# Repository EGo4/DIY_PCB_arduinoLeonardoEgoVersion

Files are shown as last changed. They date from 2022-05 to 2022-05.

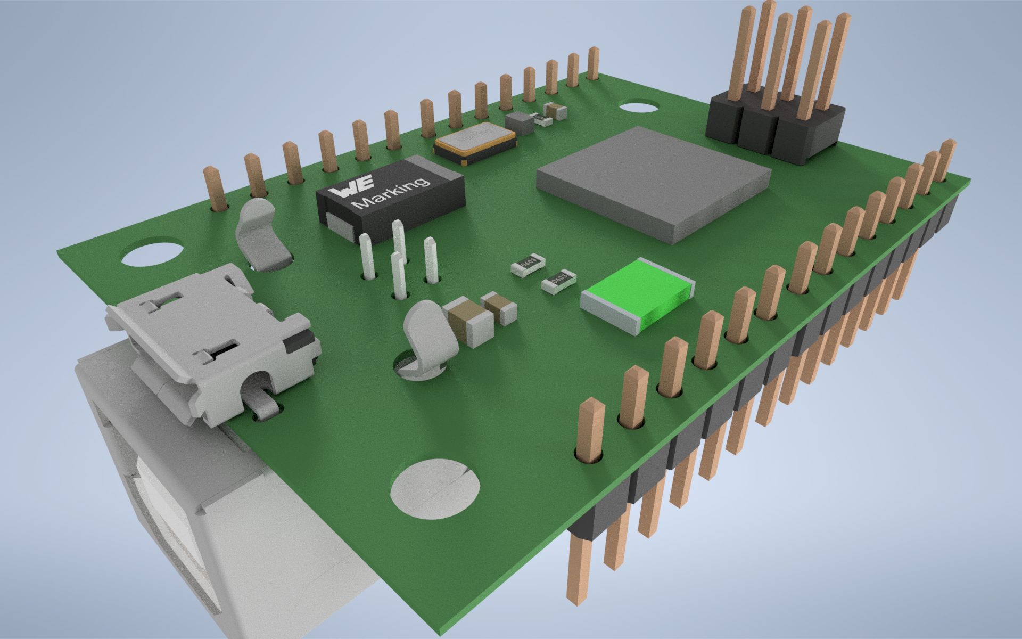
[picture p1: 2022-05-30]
Renderings/arduinoLeonardoEgoVersion.png

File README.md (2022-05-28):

# DIY_arduinoLeonardoEgoVersion
This PCB is an Atmega32u4 based microcontroller board. It can be flashed so that it reports as an Arduino Leonardo or Pro Micro. I am using it in multiple projects like a sim racing wheel for example. The files where created with Altium 18. Step file and gerber files can be found in the repository as well.

This is NOT considered to be an open-source project. Thus any commercial use is prohibited by the owner. Copying and mofying the files for private use is permitted.

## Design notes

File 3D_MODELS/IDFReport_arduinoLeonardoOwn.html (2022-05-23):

Altium customize

# IDF File Translation Report

Date: | | 04.07.2021
Time: | | 13:42:24
Elapsed Time: | | 00:00:00
PCB Filename | : | C:\Users\Eric\Documents\Simulator\PCB\arduinoLeonardoOwn\arduinoLeonardoOwn.PcbDoc
IDF Board Filename | : | C:\Users\Eric\Documents\Simulator\PCB\arduinoLeonardoOwn\.\3D_MODELS\arduinoLeonardoOwn.brd
IDF Library Filename | : | C:\Users\Eric\Documents\Simulator\PCB\arduinoLeonardoOwn\.\3D_MODELS\arduinoLeonardoOwn.pro

Errors

Back to top

Warnings

Back to top

Save Warnings

Back to top

Save Errors

Back to top

Export Warnings

Back to top

Export Errors

Back to top

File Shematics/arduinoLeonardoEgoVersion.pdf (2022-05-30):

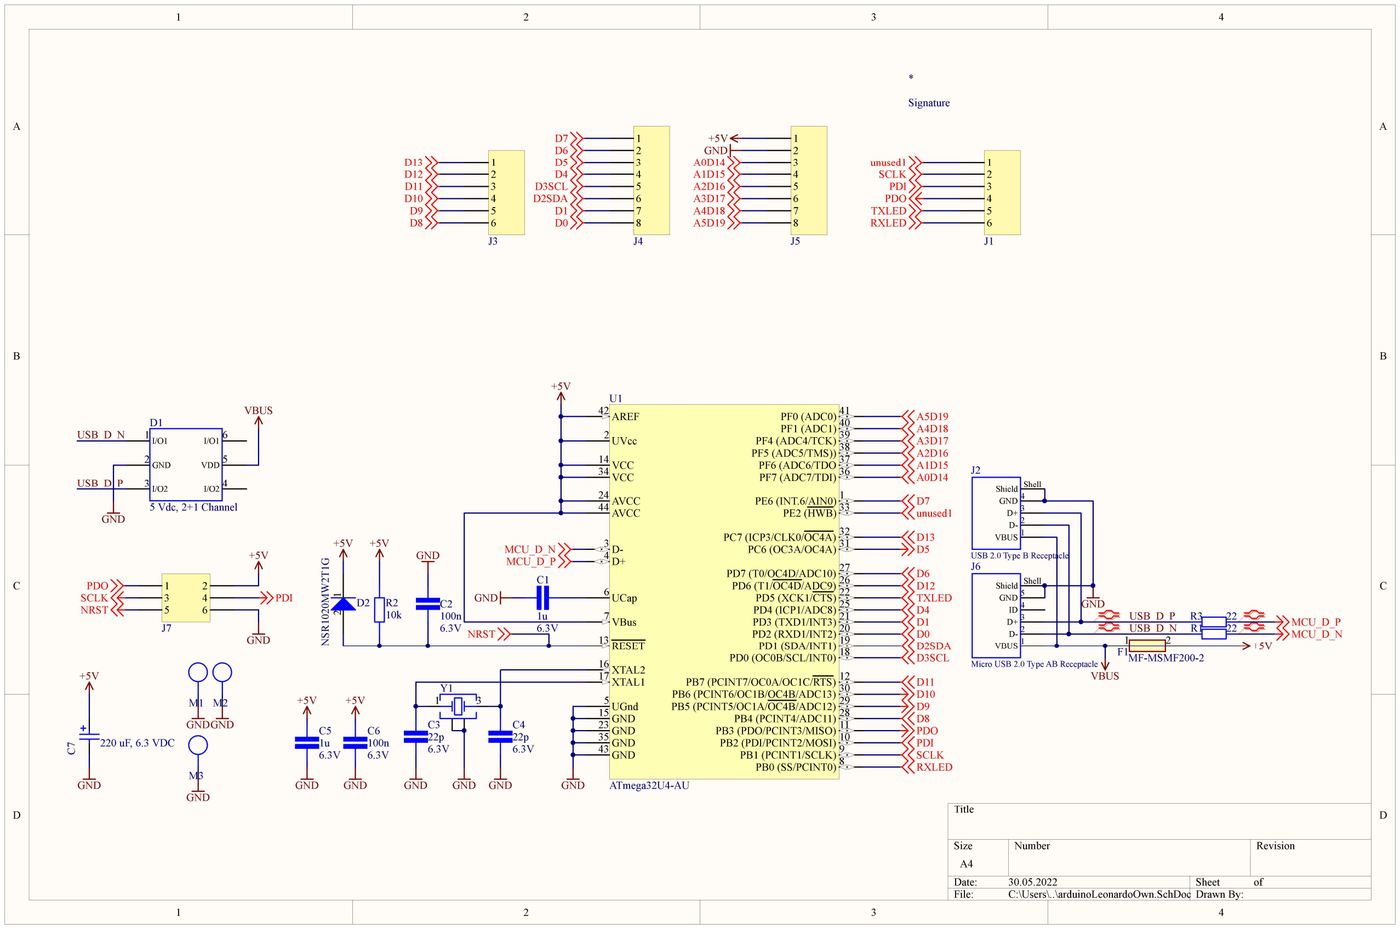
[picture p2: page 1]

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
Title

Size | Number | | Revision
A4
Date: | 30.05.2022 | Sheet | of
File: | C:\Users\..\arduinoLeonardoOwn.SchDoc Drawn By:

+5V

100n
6.3V

C6

GND

1u
6.3V

C5

GND

+5V

M3

GND

PDI

PDO
SCLK
NRST

GND

+5V C⁷ 220 uF, 6.3 VDC

GND

+5V

I/O1 1

I/O1 6

GND 2

I/O2 3

I/O2 4

VDD 5

D1

### 5 Vdc, 2+1 Channel

USB_D_N

USB_D_P

GND

VBUS

MCU_D_N

MCU_D_P USB_D_N

USB_D_P
R1 | 22
R3 | 22

+5V

VBUS

M1

GND

M2

GND

D+ 4

D- 3

AVCC 44 AVCC 24

AREF 42

XTAL2 16
XTAL1 17

VCC 34 VCC 14

VBus 7

UGnd 5

UCap 6

RESET 13

PF7 (ADC7/TDI) 36 PF6 (ADC6/TDO 37 PF5 (ADC5/TMS)) 38 PF4 (ADC4/TCK) 39 PF1 (ADC1) 40 PF0 (ADC0) 41

PE6 (INT.6/AIN0) 1

PD7 (T0/OC4D/ADC10) 27
PD6 (T1/OC4D/ADC9) 26
PD5 (XCK1/CTS) 22
PD4 (ICP1/ADC8) 25
PD3 (TXD1/INT3) 21
PD2 (RXD1/INT2) 20
PD1 (SDA/INT1) 19
PD0 (OC0B/SCL/INT0) 18

PC7 (ICP3/CLK0/OC4A) 32
PC6 (OC3A/OC4A) 31

PB6 (PCINT6/OC1B/OC4B/ADC13) 30 PB5 (PCINT5/OC1A/OC4B/ADC12) 29 PB4 (PCINT4/ADC11) 28
PB3 (PDO/PCINT3/MISO) 11
PB2 (PDI/PCINT2/MOSI) 10
PB1 (PCINT1/SCLK) 9
PB0 (SS/PCINT0) 8

GND 43 GND 35

GND 15

UVcc 2

PE2 (HWB) 33

PB7 (PCINT7/OC0A/OC1C/RTS) 12

GND 23

U1

ATmega32U4-AU

D9

D10

PDI

PDO

SCLK

D5

A1D15
A0D14

A3D17
A2D16

+5V

MCU_D_N
MCU_D_P
GND | GND

22p
6.3V

C4
22p
6.3V

C3

GND | GND

1u
6.3V

C1
GND
10k

R2

+5V +5V

NRST ¹ ²

D2 NSR¹⁰²⁰MW²T¹G | 100n

6.3V

C2

GND

A4D18

A5D19

D7
unused1

D6

D4

D2SDA
D3SCL

TXLED

D13

RXLED

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
D2SDA

D3SCL

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
A5D19

A1D15

A0D14

A3D17

A2D16

A4D18

+5V
GND

Shield Shell

VBUS 1

D- 2

D+ 3

ID 4

GND 5

J6

Micro USB 2.0 Type AB Receptacle

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
SCLK

unused1

TXLED
RXLED

VBUS 1

D- 2

D+ 3

GND 4

Shield Shell

J2

USB 2.0 Type B Receptacle

1 2
3 4
5 6
J7

1 3

Y1

*

Signature

1 2
F1MF-MSMF200-2

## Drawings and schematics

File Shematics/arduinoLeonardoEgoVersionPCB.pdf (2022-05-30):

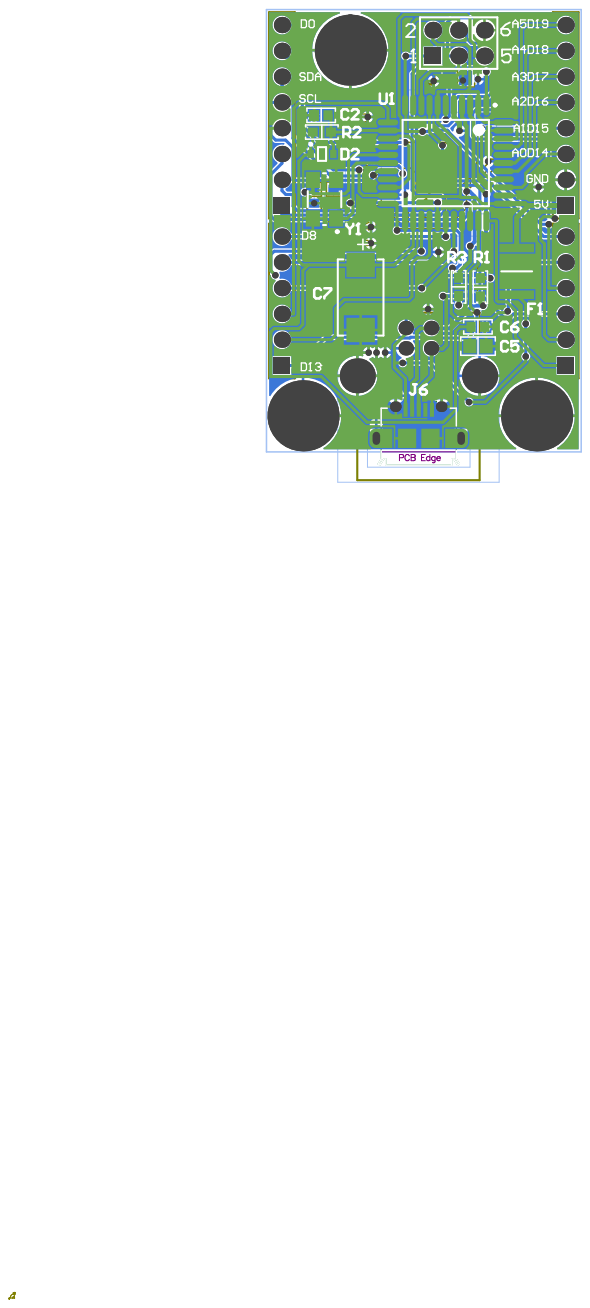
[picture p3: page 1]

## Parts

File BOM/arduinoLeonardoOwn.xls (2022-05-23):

Comment | Description | Designator | Footprint | Quantity | Value | DesignItemId | Part Number | PartNumber
5 Vdc, 2+1 Channel | TVS Diode - High Speed Series WE-TVS, SOT563, 5 Vdc, 2+1 Channel | D1 | WE-TVS_High Speed_SOT563 | 1 |  | 82400152 | 82400152
16MHz, +/-50ppm, 18pF | WE-XTAL Quartz Crystal, size CFPX-104, 16MHz, +/-50ppm, 18pF | Y1 | WE-XTAL_CFPX-104 | 1 |  | 830030819 | 830030819
220 uF, 6.3 VDC | Aluminum Polymer Capacitors WCAP-PHGP, 220 uF, 6.3 VDC | C7 | WCAP-PHGP_7.3x4.3x1.9 | 1 |  | 875015119006 | 875015119006
61300611121 | WR-PHD 2.54 mm THT Pin Header, 6p | J1, J3 | 61300611121 | 2 |  | 61300611121 | 61300611121
61300621121 | WR-PHD 2.54 mm THT Dual Pin Header, 6p | J7 | 61300621121 | 1 |  | 61300621121 | 61300621121
61300811121 | WR-PHD 2.54 mm THT Pin Header, 8p | J4, J5 | 61300811121 | 2 |  | 61300811121 | 61300811121
ATmega32U4-AU | 8-bit AVR Microcontroller, 2.7-5.5V, 16MHz, 32KB Flash, 1KB EEPROM, 2.5KB SRAM, USB Controller, 44-pin TQFP, Industrial Grade (-40°C to 85°C), Ext Osc | U1 | 44ML_M | 1 |  | CMP-0095-00285-2
MF-MSMF200-2 | Fuse | F1 | FUSC4632X85N | 1 |  | MF-MSMF200-2
Micro USB 2.0 Type AB Receptacle | Micro USB 2.0 Type AB, Receptacle, Horizontal, SMT | J6 | 629105150921 | 1 |  | 629105150921
NSR1020MW2T1G | Schottky Barrier Diode, 2-Pin SOD-323, Pb-Free, Tape and Reel | D2 | ONSC-SOD-323-2-477-02_V | 1 |  | CMP-1055-00471-1 |  | NSR1020MW2T1G
Signature |  |  | Signature | 1 |  | Signature
SMD Capacitor; 1u; 6.3V | Capacitor with multiple Footprints | C1, C5 | CAP 0805/2012 | 2 | 1u | SMD Capacitor
SMD Capacitor; 22p; 6.3V | Capacitor with multiple Footprints | C3, C4 | CAP 0603/1608 | 2 | 22p | SMD Capacitor
SMD Capacitor; 100n; 6.3V | Capacitor with multiple Footprints | C2, C6 | CAP 0603/1608 | 2 | 100n | SMD Capacitor
SMD Resistor; 10k | Resistor with multiple footprints | R2 | STACKPOLE CSR0603 | 1 | 10k | SMD Resistor
SMD Resistor; 22 | Resistor with multiple footprints | R1, R3 | STACKPOLE CSR0603 | 2 | 22 | SMD Resistor
USB 2.0 Type B Receptacle | USB 2.0 Type B, Receptacle, Horizontal, THT | J2 | 61400416121 | 1 |  | 61400416121
